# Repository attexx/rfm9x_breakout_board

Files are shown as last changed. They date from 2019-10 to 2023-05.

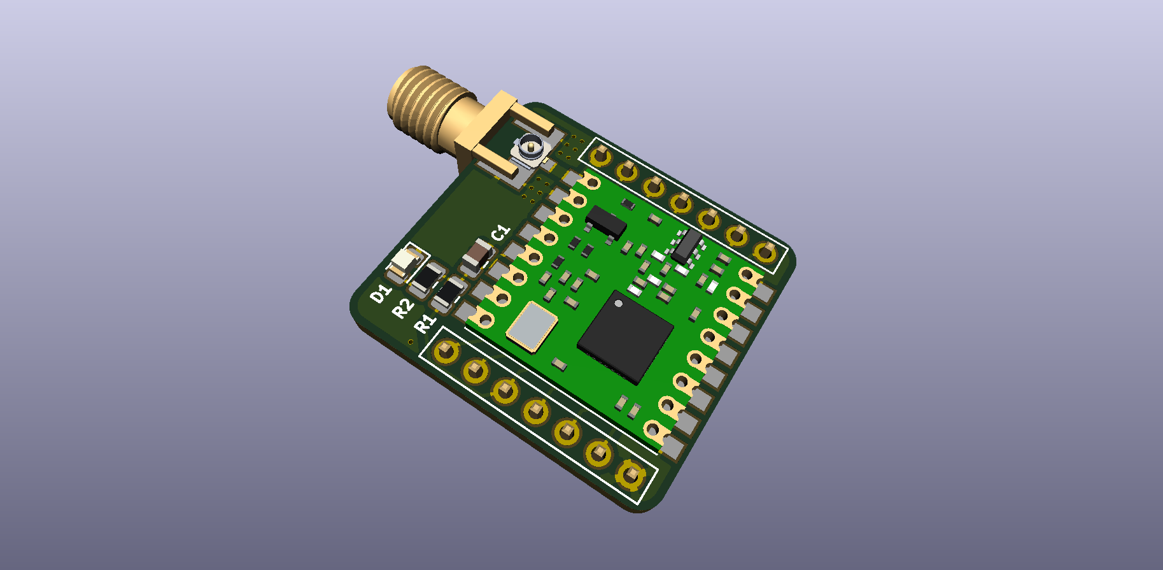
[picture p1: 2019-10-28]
KiCAD/rev.1b/images/02.png

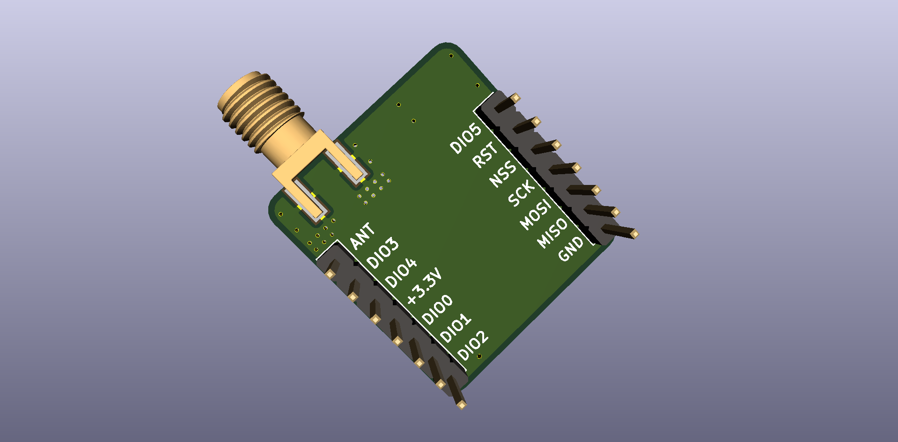
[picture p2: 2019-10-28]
KiCAD/rev.1/images/02.png

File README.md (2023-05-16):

# RFM9x Breakout Board

</br>



### Description

The RFM9x Breakout Board is a breadboard friendly PCB, converting the 2mm pitch connectors on the HopeRF modules to a more user friendly 2.54mm (0.100″) pitch footprint, used in standard breadboards. Using the breadboard, the developers can easily create IoT modules with 430MHz, 868MHz or 905MHz in their projects and add LoRaWAN capabilities to them.

### Features

- small size
- breadboard friendly (pin spacing 2.54mm)
- the board includes combined footprint for SMA edge as well as SMD u.Fl antenna connector, so both connectors can be applied separately or together depends on what is needed
- optional circuit for power indication
- optional pullup resistor to keep high voltage level on NCC pin in case the RFM95W/96W/98W module is connected to MCU that requires programming via FTDI

### Schematic

_schematic_<br />


Nothing special on the schematic. The components R1, R2 and D1 are optional and can be omitted if not needed. R1 is used as pullup to keep high voltage level on the NCC pin. This allows programming the RFM95W/96W/98W module in case the board is interfaced to external microcontroller and ISP is used as a programming interface. R2 and D1 are used as power indication.

### Boards

#### Revision 1b:

Updates in revision 1b include:
- added support for SMD u.Fl antenna connector
- added open source hardware logo to the layout of the board

_top side_<br />


_bottom side_<br />


#### Revision 1:

Initial revision, obsolete.

_top side_<br />


_bottom side_<br />


### BOM

All components are 0805 sized and you can buy them everywhere.

| id | designator | value | description | quantity | datasheet | supplier | note |
|----|---|---|---|---|---|---|---|
| 1  | R1 | 10k | Resistor SMD 0805  | 1 | | | optional |
| 2  | R2 | 330 | Resistor SMD 0805  | 1 | | | optional |
| 3  | C1 | 10uF | Capacitor SMD 0805 | 1 | | | required |
| 4  | D1 | LED | LED 0805 | 1 | | | optional |
| 5  | J1 | Connector | SMD Edge Connector | 1 | | | optional |
| 6  | J1 | Connector | SMA u.Fl Connector | 1 | | | optional |
| 7  | U1 | RFM9xW | RFM9xW module | 1 | [datasheet][a173d720] | HopeRF | required |

[a173d720]:https://www.hoperf.com/data/upload/portal/20190801/RFM95W-V2.0.pdf "RFM95x"

### Project status

The most recent version (rev. 1b) is tested and works fine. Previous version (rev. 1) is still valid but obsolete, therefore it is not available for purchase.

### Purchase

The board can be purchased from the [AISLER.net](https://aisler.net/) web store by clicking on this [link](https://aisler.net/p/BNYBJOFL). You can also try to purchase it from 
the [PCBs.io](https://PCBs.io/share/4QJV1) web store, but be aware that recently this site has been inactive, so ordering the board through it may not be successful.

## License

<br />

Copyright © 2019 Boyan Nedkov. All rights reserved.<br />
Licensed under a [Creative Commons Attribution-NonCommercial 4.0 International License][1]. For permissions beyond the scope of this license please [contact me][2] so we can arrange a simple agreement.

[1]: http://creativecommons.org/licenses/by-nc/4.0/
[2]: mailto:attexx@gmx.com

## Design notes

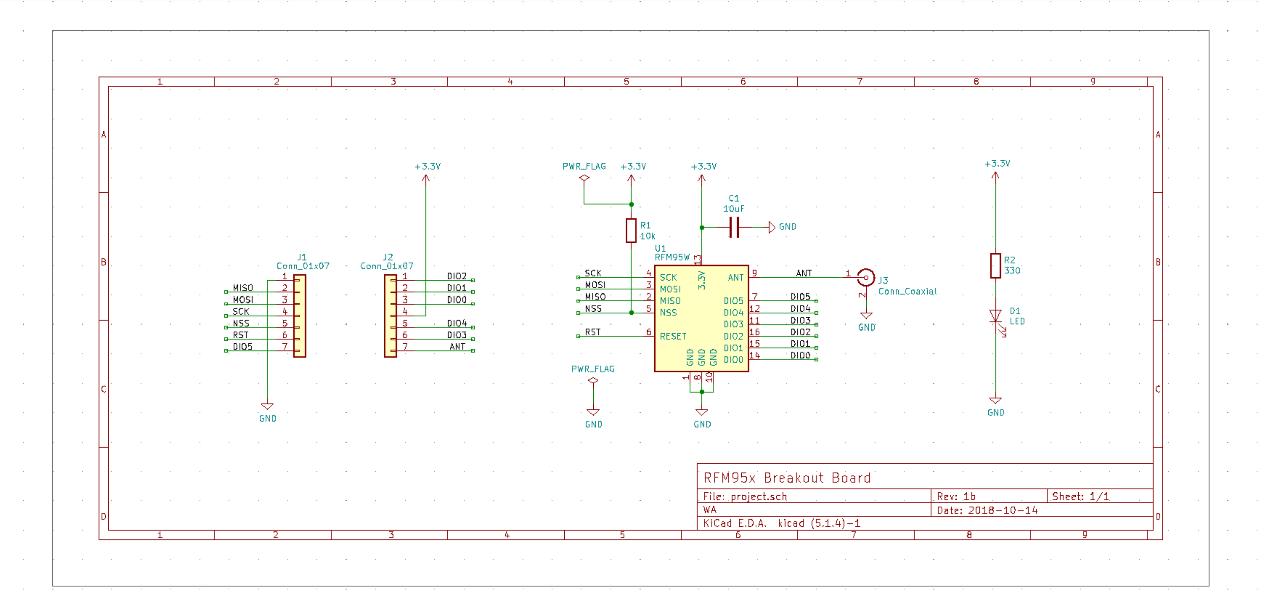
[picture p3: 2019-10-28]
KiCAD/rev.1b/images/schematic.png

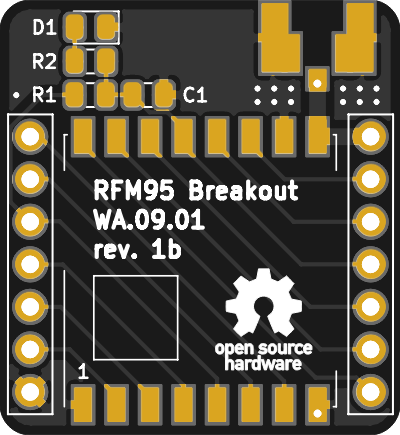
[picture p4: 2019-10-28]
KiCAD/rev.1b/images/top.svg.s.png

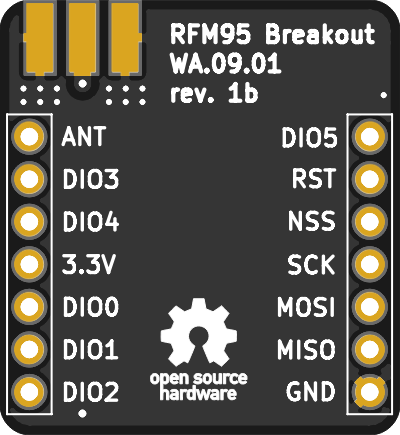
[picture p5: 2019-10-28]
KiCAD/rev.1b/images/bottom.svg.s.png

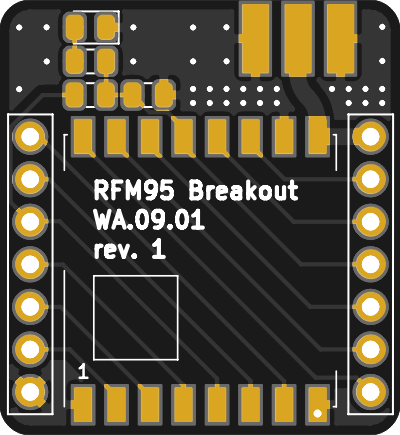
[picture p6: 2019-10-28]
KiCAD/rev.1/images/top.svg.s.png

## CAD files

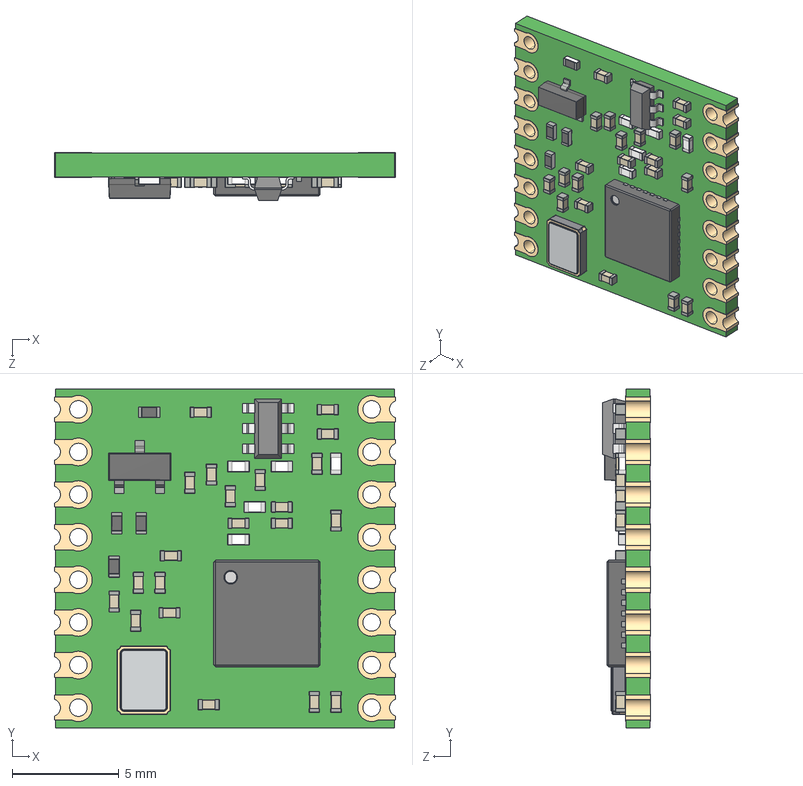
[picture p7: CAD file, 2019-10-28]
KiCAD/rev.1/lib_3D/RFM9xW.step
16.0 x 15.9 x 2.23 mm
Board
Cap0402 x 21
SW3dPS-inductor_0402_white x 5
SW3dPS-SOT-23-6
QFN28
TXC_7M
Res0402 x 4
User_Library-3-lead_sot23-3
Goldcontact x 16

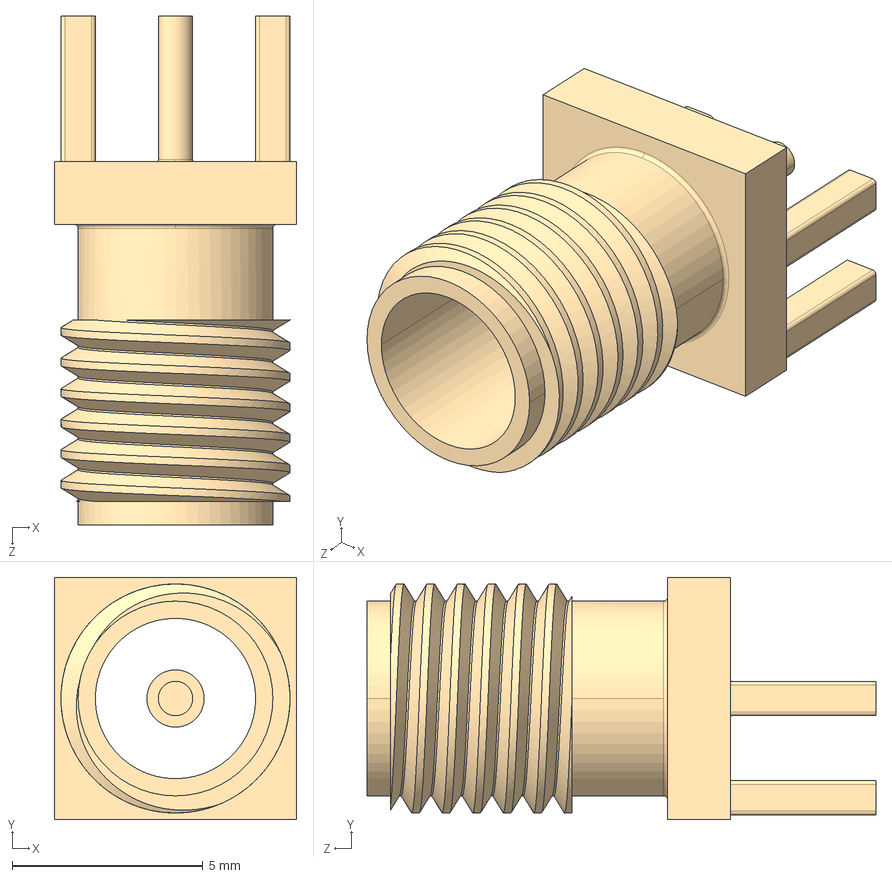
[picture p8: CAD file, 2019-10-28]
KiCAD/rev.1/lib_3D/Connector_Coaxial_SMA_edge_clear.step
6.35 x 6.35 x 13.3 mm

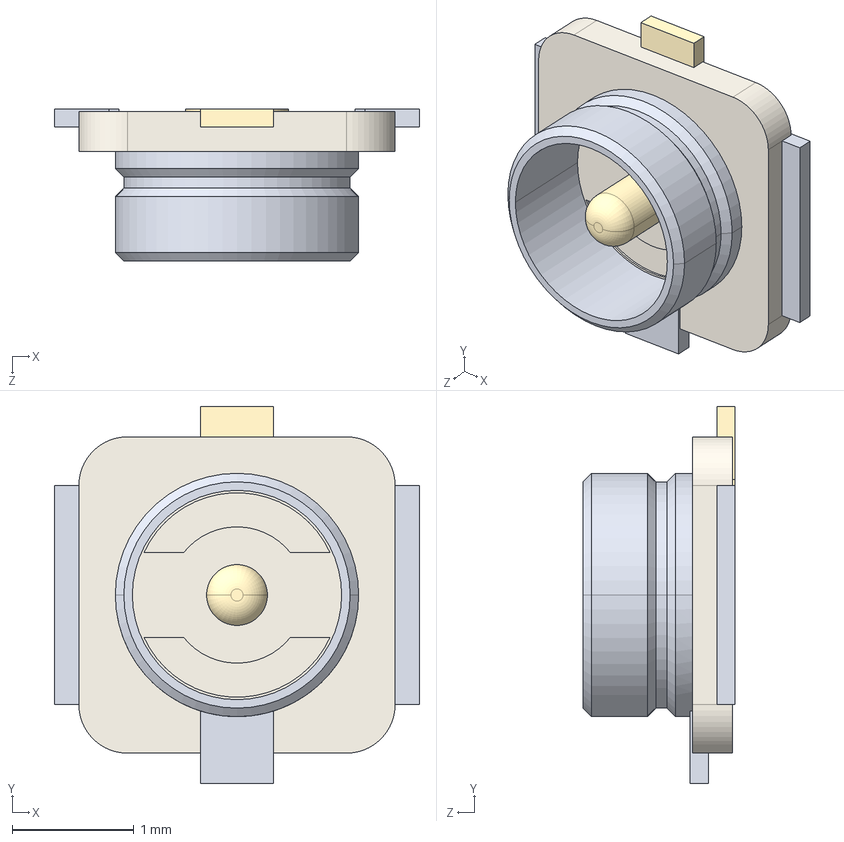
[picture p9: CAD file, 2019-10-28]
KiCAD/rev.1b/lib_3D/Connector Coaxial U.FL_Hirose_U.FL-R-SMT-1_Vertical.step
3.00 x 3.10 x 1.25 mm

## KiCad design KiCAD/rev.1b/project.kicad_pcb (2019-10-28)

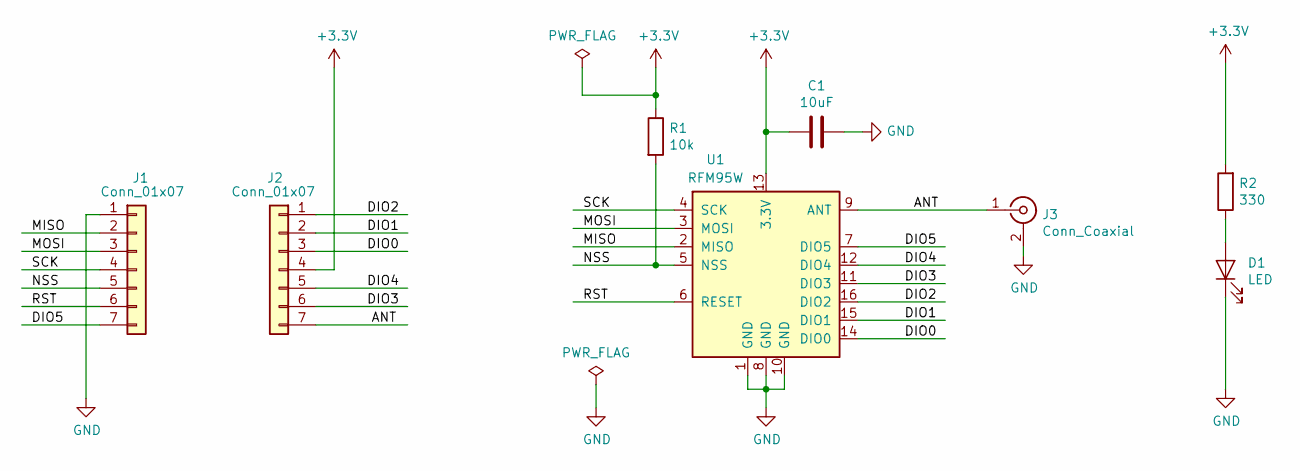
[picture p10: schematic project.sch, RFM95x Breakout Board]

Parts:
C1: 10uF; C_0805_2012Metric
D1: LED; LED_0805_2012Metric
J1, J2: Conn_01x07; PinHeader_1x07_P2.54mm_Vertical_2
J3: Conn_Coaxial; Connector_Coaxial_SMA_edge_combined
R1: 10k; R_0805_2012Metric
R2: 330; R_0805_2012Metric
U1: RFM95W

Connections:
+3V3: C1.2, J2.4, R1.1, R2.2, U1.13 (3.3V)
/ANT: J2.7, J3.1 (In), U1.9 (ANT)
/DIO0: J2.3, U1.14 (DIO0)
/DIO1: J2.2, U1.15 (DIO1)
/DIO2: J2.1, U1.16 (DIO2)
/DIO3: J2.6, U1.11 (DIO3)
/DIO4: J2.5, U1.12 (DIO4)
/DIO5: J1.7, U1.7 (DIO5)
/MISO: J1.2, U1.2 (MISO)
/MOSI: J1.3, U1.3 (MOSI)
/NSS: J1.5, R1.2, U1.5 (NSS)
/RST: J1.6, U1.6 (RESET)
/SCK: J1.4, U1.4 (SCK)
GND: C1.1, D1.1 (K), J1.1, J3.2 (Ext), U1.1 (GND), U1.8 (GND), U1.10 (GND)
unnamed: D1.2 (A), R2.1

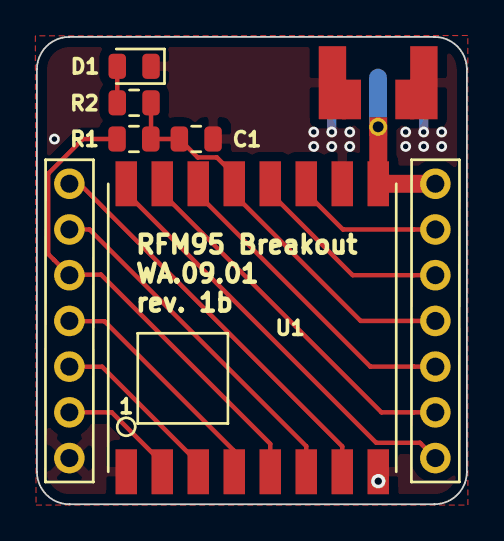
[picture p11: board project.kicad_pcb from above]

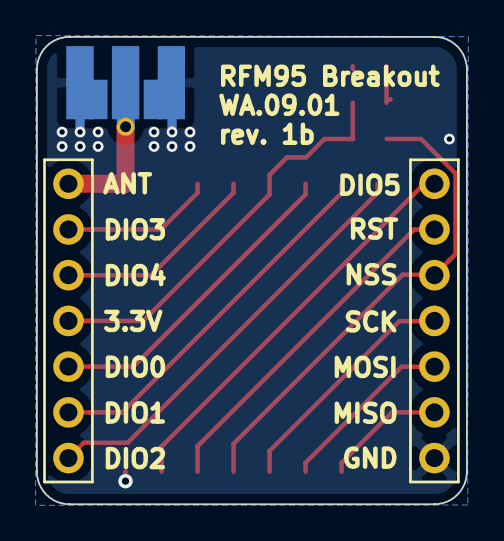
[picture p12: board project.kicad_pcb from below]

Board: 2 copper layers, 23.9 x 26.0 mm, 8 parts (3 on the bottom side), 15 nets.

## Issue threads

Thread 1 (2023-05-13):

Pcbs.io link dead

BenCos17, 2023-05-13:
Just went to the pcbs.io link and it gives a domain for sale page so I assume they don't exist anymore btw

attexx, 2023-05-16:
you could order your copies of the RFM95x breakout board from the AISLER manufacturing site using the following url:  https://aisler.net/p/BNYBJOFL

BenCos17, 2023-05-16:
yep
might be worth editing that part out btw
